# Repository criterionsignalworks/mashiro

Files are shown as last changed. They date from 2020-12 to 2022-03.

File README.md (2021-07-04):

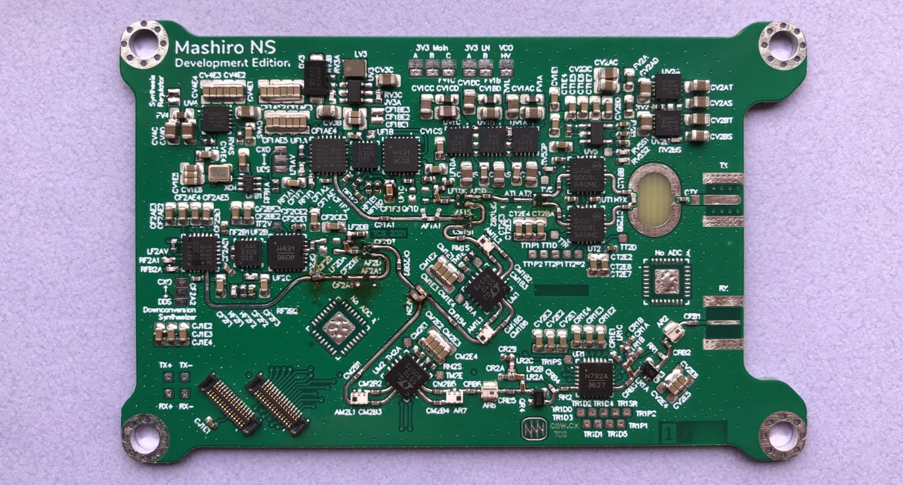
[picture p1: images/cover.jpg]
 

# Project Mashiro 

Explore synthetic aperture radar imaging by building real hardware. 

Currently working on RF front end, processing algorithm, and programming microcontrollers. 

## Abstract 

The ability for autonomous robots to understand their surroundings is instrumental for their ability to interact and navigate the environment safely and effectively. Current autonomous platforms rely heavily on LIDAR and optical camera sensors due their high resolution, compact form factor, and integration accessibility. 

In emergent applications for robotics like search and rescue as well as situations that push the envelope within mainstream applications, harsh environmental conditions like dust, rain, fog, or snow limit the performance of contemporary optical sensor suites. 

Radar imaging uses lower frequencies with wavelengths in the millimeter to centimeter range, while optical methods utilize wavelengths in the hundreds of nanometer range. The longer wavelength of radiofrequency sensing increases dependability in certain situations at the expense of yielding inferior resolution. 

Our system operates at 5.8 GHz for improved immunity from environmental interference compared to typical 77 GHz automotive systems, as well as increased resolution from radar platforms that operate at an even lower frequency. We also apply Synthetic Aperture Radar imaging technique to enhance effective resolution by utilizing the motion of the platform to synthesize a larger virtual aperture aided by computation in hardware. 

We developed an alternative radar architecture featuring two independent synthesizers and downconverters which allow much greater flexibility and performance compared to existing systems which produce baseband at near zero frequency. Our platform is also physically compact, economical, and flexible in realization, which makes it suitable for deployment in size constrained applications and easily extended to fit specific use cases. 

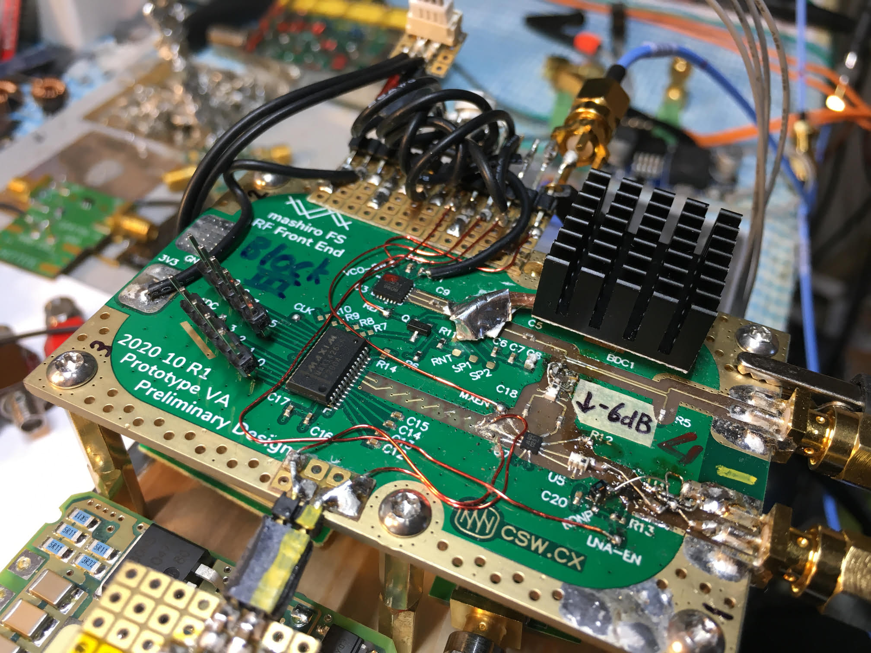
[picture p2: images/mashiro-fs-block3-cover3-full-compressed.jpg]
 

## Current status 

As of March 2021, we have begun additional exploration and development of a processing script for data captured from analog front end. Current plans include use of range migration algorithm presented in §10 of *Spotlight Synthetic Aperture Radar* with modifications to motion correction element. Additionally, we developed [CS Gain Block](https://github.com/criterionsignalworks/gain-block) for rapid prototyping the receive section for our next hardware iteration. 

As of February 2021, we have demonstrated basic remote sensing capabilities with our hardware. We are able to detect motion up to about 7 meters (limited by testing environment) in FMCW mode, and effectively around 5 meters in CW (doppler) mode. 

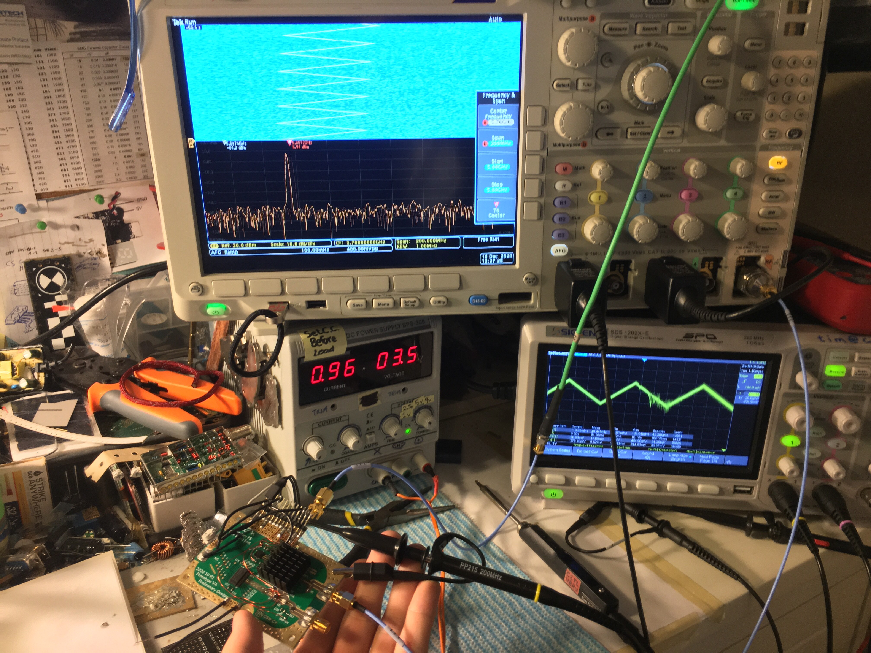
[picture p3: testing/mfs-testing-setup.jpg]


As of late December 2020, we have demonstrated the capability of our high speed analog front end, successfully transmitting a frequency modulated carrier waveform and observing some frequency mixing by the receive section. Additionally, we have begun preliminary prototyping of the digital control, sequencing, and data acquisition systems using our in-house STM32 based microcontroller development platform [CS Ranka](https://github.com/criterionsignalworks/ranka). We have verified the viability of our software development toolchain, using IAR Systems Embedded Workbench development environment. 

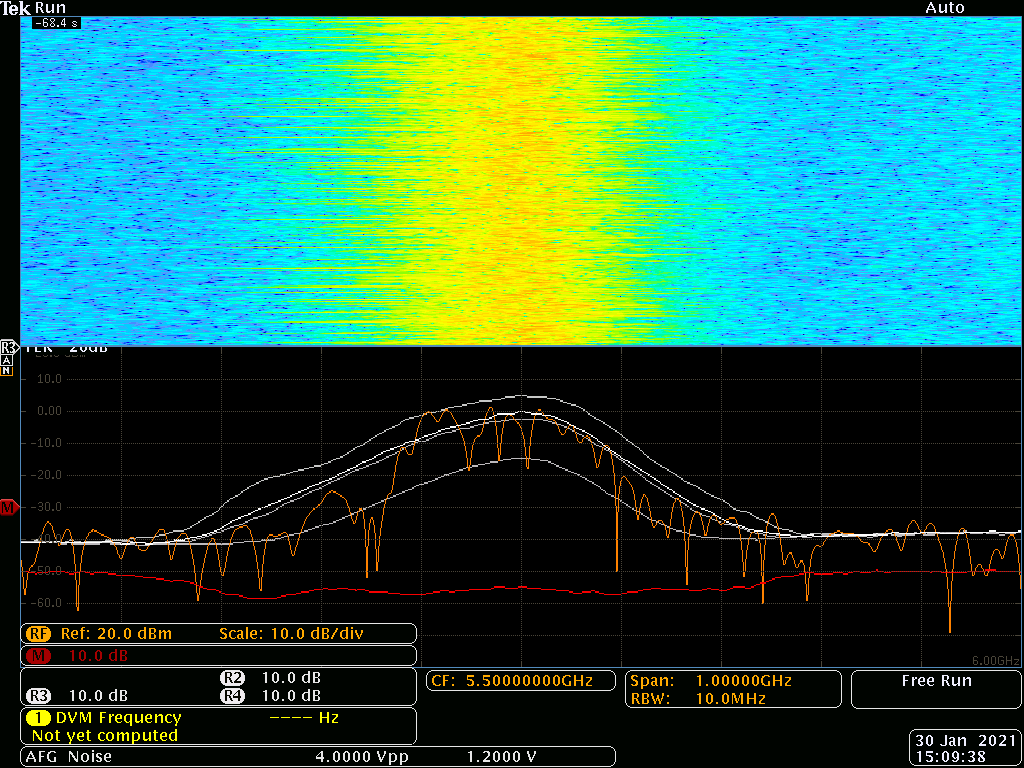
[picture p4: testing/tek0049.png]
 

Project and repository are work in progress, more updates coming some time soon.

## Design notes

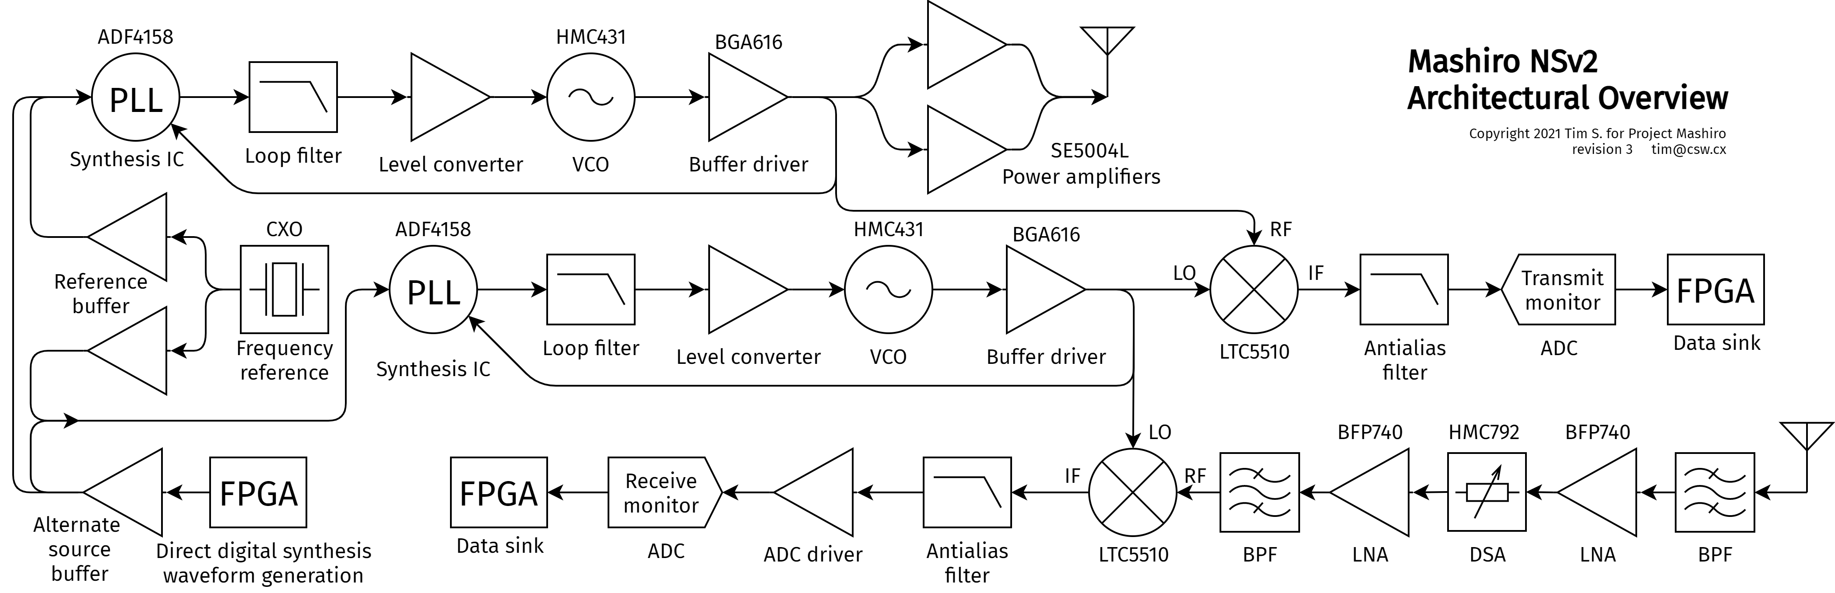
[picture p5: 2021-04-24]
images/mashiro-nsv2-block-diagram-r3.png

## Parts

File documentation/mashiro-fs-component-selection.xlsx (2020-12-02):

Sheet: BOM
CSW Design Documentation |  | CS Mashiro - Mashiro FS Component Selection
TCS July 2020 |  | Selected components
Power amplifier | SE5004L | $2.58 | Max RF input 6dBm
LNA | SKY65404 | $0.50
VCO | HMC431LP4 | $20.00 | Pout 2dbm
MCU | STM32F722RET6 | $6.00
ADC Option 1 | AD9200 | $7.00 | ???????????
ADC Option 2 | MAX1426 | $5.00
Analog front end? | AFE5401 | $23.00
Baseband amplifier | LT6230/LT6232 | $4.00
Baseband amplifier | LT6237 | $4.00
Baseband amplifier | TLV3541 | $0.80
Rx band select filter | DEA205425BT | $0.16 | https://lcsc.com/product-detail/RF-Filters_TDK_DEA205425BT-2028A4_DEA205425BT-2028A4_C136229.html
Heterodyning mixer | ADL5801 | $11.00 | used in fmcw2
Heterodyning mixer | LTC5562 | $12.00 | performance looks good

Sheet: Signal Chains
VCO (POUT: 2dbm)
Power AMP (6dbm)
Component | In Min | In Max | In N/A | Out Min | Out Max | Out N/A
VCO |  |  |  | -1dbm | 2dbm
Power AMP | 6dbm

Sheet: ADC
 | CSW Design Documentation |  | CS Mashiro - Mashiro FS Component Selection
 | TCS July 2020 |  | Signal digitization - ADC
 | Design target: 12-bit, 80MHz
 | MAX1426 | AD9200 | 3PA1030 | ADC12020 | ADC08351 | ADC1173
Est. Unit cost (1@10) | $5.00 | $7.00 | $2.50 | $4.20 | $2.00 | $3.00
Manufacturer | Maxim | Analog Devices | 3PEAK | TI/National Semi | TI/National Semi | TI
Bit depth | 10 bit | 10 bit | 10 bit | 12 bit | 8 bit | 8 bit
Sample rate | 10 Msps | 20 Msps | 50 Msps? | 20 Msps | 42 Msps | 15 Msps

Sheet: MCU
 |  | CSW Design Documentation |  | CS Mashiro - Mashiro FS Component Selection
 |  | TCS July 2020 |  | Computation and communication - MCU/Microcontroller
 |  | MKL26Z | STM32F103C8T6 | STM32F722RET6 (https://lcsc.com/product-detail/ST-Microelectronics_STMicroelectronics_STM32F722RET6_STM32F722RET6_C118207.html) | LPC4320 | ESP32-PICO-D4
 | Est. Unit cost (1@10) |  |  | $5.13 | $7.60
 | Manufacturer | NXP/Kinetis | STMicroelectronics | STMicroelectronics | NXP | Espressif
 | Family/Toolchain |  | STM32 | STM32 |  | ESP32
 | Core architecture |  | Cortex M3 | Cortex M7 | Cortex M4/M0 | 2x Xtensa LX6
 | Frequency |  | 72MHz | 216MHz | 204MHz | 240MHz
 | Package |  | LQFP-48
Memory | Flash |  | 64KB/128KB | 512KB | 0KB | 448KB
 | SRAM |  | 20KB | 256KB | 256KB | 8KB + 8KB
 | EEPROM
Comms | USART |  | 3x |  |  | 3x
 | I2C |  | 2x 18Mbit/s | 3x |  | 3x 80MHz
 | SPI |  | 2x |  |  | 2x 400kbit/s
 | USB |  | 2.0 FS
 | CAN

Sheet: RF Amplifiers
 | CSW Design Documentation |  | CS Mashiro - Mashiro FS Component Selection
 | TCS July 2020 |  | Amplifiers
 | Design target: may vary
 | MGA-25203 (https://np.infinity-electronic.hk/datasheet/8d-MGA-25203-TR1G.pdf) | BGA622 (https://lcsc.com/product-detail/RF-Amplifiers_Infineon-Technologies_BGA622H6820_Infineon-Technologies-BGA622H6820_C132318.html) | TQP7M9101 (https://lcsc.com/product-detail/RF-Amplifiers_Qorvo-TQP7M9101_C415713.html) | SE5004L (https://lcsc.com/product-detail/Others_Skyworks-Solutions_SE5004L-R_Skyworks-Solutions-SE5004L-R_C210263.html) | SKY65404 (https://lcsc.com/product-detail/Others_Skyworks-Solutions_SKY65404-31_Skyworks-Solutions-SKY65404-31_C210262.html) | SST11LP12 (http://ww1.microchip.com/downloads/en/DeviceDoc/75047A.pdf)
Applicaton | PA | LNA | Gain block | PA | LNA | PA
Est. Unit cost (1@10) |  | $0.39 | $1.96 | $2.58 | $0.50
Manufacturer | Avago | Infineon | Qorvo | Skyworks | Skyworks | SST/Microchip
Band | 4.9-5.9 GHz |  | 0.4-5 GHz |  | 4.9-5.9 GHz | 4.9-5.9 GHz
Gain/output | 30 dB (5.4GHz 3V3) 32 dBm (64QAM) |  | 17.5 dB gain @2.14 25 dBm P1dB | 32 dB gain 3% EVM @26 dBm | 7 dBm IIP3 13 dB gain | 3% EVM 20dBm 31 dB gain @5.4
Noise figure |  | 1 dB at 1.575 GHz |  |  | 1 dB
Impedance | 50Ω |  | Matched(?)
Supply voltage | 3-5V |  | 5V | 3-5.5V (Vref 2.85V) | 2.8-5V
Gain flatness | <1dB, any 20MHz | Not PA

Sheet: Baseband Amplifiers
 | CSW Design Documentation |  | CS Mashiro - Mashiro FS Component Selection
 | TCS July 2020 |  | Amplifiers
 | Design target: may vary
 |  | Est. Cost | Manufacturer | Max BW (Unity) | Noise | Slew rate | CMR | R-R capability
range comp IF amp | LT6230/LT6232 (https://www.analog.com/media/en/technical-documentation/data-sheets/623012fc.pdf) | $4.00 | LT | 215MHz | 1.1nV/√Hz | 70V/us | 90-115dB | Yup
 | LT6236 (https://datasheet.octopart.com/LT6236CS6%23TRMPBF-Linear-Technology-datasheet-32866028.pdf) | $4.00 | LT | 215MHz | 1.1nV/√Hz | 70V/us | 90-115dB | Yup
 | LM318MX (https://lcsc.com/product-detail/General-Purpose-Amplifiers_Texas-Instruments_LM318MX-NOPB_Texas-Instruments-Texas-Instruments-LM318MX-NOPB_C128749.html) | $0.80 | TI | 15MHz |  | 50V/us |  | No?
 | LM358DT (https://lcsc.com/product-detail/General-Purpose-Amplifiers_STMicroelectronics-LM358DT_C9418.html) | $0.05 | ST | 1.1MHz |  |  |  | No
fmcw2 adc | LT1817 (https://www.analog.com/media/en/technical-documentation/data-sheets/181567fb.pdf) | $3.70 | LT | 220MHz | 6nV/√Hz | 1500V/us
 | ADA4891-1 (https://www.analog.com/media/en/technical-documentation/data-sheets/ADA4891-1_4891-2_4891-3_4891-4.PDF) | $1.50 | AD | 220MHz (-3dB) | 9nV/√Hz | 170V/us |  | Yes | + | low cost
 | LT1722 (https://www.analog.com/media/en/technical-documentation/data-sheets/172234fb.pdf) | $2.80 | LT | 220MHz | 3.8nV/√Hz | 70V/us |  |  | + | rf amp
 | ADA4807-1 (https://www.analog.com/media/en/technical-documentation/data-sheets/ADA4807-1_4807-2_4807-4.pdf) | $4.70 | AD | 180MHz (-3dB) | 3.1nV/√Hz | 225V/us |  | Yes
 | AD8057 (https://www.analog.com/media/en/technical-documentation/data-sheets/AD8057_8058.pdf) | $2.60 | AD | 325MHz (-3dB) | 7nV/√Hz | 1000V/us
 | TLV3541 (https://www.ti.com/lit/ds/symlink/tlv3541.pdf?ts=1596304995804) | $0.80 | TI | 200MHz Unity | 7.5nV/√Hz | 150V/us |  | Yes | + | low cost

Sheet: CPLD
 | CSW Design Documentation |  | CS Mashiro - Mashiro FS Component Selection
 | TCS July 2020 |  | Front side signal processing - FPGA
 | EPM3032A (https://lcsc.com/product-detail/New-Arrivals_Altera-EPM3032ATC44-10N_C500865.html)
Est. Unit cost (1@10) | $1.96
Manufacturer | Altera
Family/Toolchain | MAX3000A | MachXO2
IO voltage | 5V, 3V3, 2V5
Package logical voltage | 3V3
Clock speed | 227.3MHz
Chosen package | TQFP-44
Min. Pin to pin logic delay | 4.5ns
Logic cells | 600(?)
Macrocell count | 32
Logic array blocks | 2

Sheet: Moonshot
ADC | https://www.analog.com/en/products/ltc2226.html#product-samplebuy
 | https://www.analog.com/en/products/ltc2227.html#product-samplebuy
 | https://www.analog.com/en/products/ltc1745.html#product-samplebuy
VCO | https://www.analog.com/en/products/hmc431.html#product-discussions

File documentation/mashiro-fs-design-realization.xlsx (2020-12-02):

CSW.cx - TCS 2020 - Mashiro FS Design Realization |  |  |  |  |  |  |  |  |  |  |  |  | + | ? | = | X | * |  | W
 |  |  |  |  |  | Supply |  |  | Approval |  |  | Library |  |  |  |  | Schematic |  |  |  | PCB |  |  |  | Fabrication
Component | Function | Confidence | Comment & Notes | Ballpark price | Ballpark qty | Selection | Procurement | Check | TCS | PS | Check | Footprint | Schematic | Symbol | Check |  | Essential | Functional | Other | Check | Placement | Route | Gloss | Check | Physical | SMT Align | SMT Paste clear | Final | Check
STM32F722RET6 | Orchestration | + | SMT or rework? | $7.08 | 1 | + | LC | + | + | + | + | + | + | + | + |  | + | X | X | X | X | X | X | X | X | ? |  | X | X
HMC431LP4 | VCO | + |  | Sample | 1 | + | + | + | + | + | + | + | + | + | + |  | + | + | X | X | X | X | X | X | X | * | X | X | X
SKY65404 | LNA | + |  | $0.59 | 1 | + | SM | + | + | + | + | + | + | + | + |  | + | + | X | X | X | X | X | X | X | X | * | X | X
SE5004L | Tx PA | + |  | $2.97 | 1 | + | SM | + | + | + | + | + | + | + | + |  | + | + | X | X | X | X | X | X | X | X | * | X | X
LTC2227 | ADC | W | Selection in progress |  | 1 | ? | ? | ? | + | = | = | X | X | X | X |  | X | X | X | X | X | X | X | X | X | * | X | X | X
MAX1426 | ADC | + |  | Sample | 1 | + | + | + | + | = | = | + | + | + | + |  | X | X | X | X | X | X | X | X | X | * | X | X | X
LTC5562 | Mixer | W |  |  | 1 | = | W | X | + | = | = | + | + | + | + |  | + | + | X | X | X | X | X | X | X | * | X | X | X
TLV3541 | Opamp | + |  |  | 6? | + | AR | + | + | + | + | + | + | + | + |  | X | X | X | X | X | X | X | X | X | * | X | X | X
2mm Header | Interconnect | + |  | $0.14 | 1 | + | LC | + | + | + | + | + | + | + | + |  | + | X | X | X | X | X | X | X | X | * | X | X | X
Reverse coupler | Microstrip element | * |  | X |  | * | * | * | + | * | + | + | + | + | + |  | + | + | X | X | X | X | X | X | X | * | X | X | X
Mitered corner | Microstrip element | * |  | X |  | * | * | * | + | * | + | + | + | + | + |  | X | X | X | X | X | X | X | X | X | * | X | X | X
HHM1595A1 | Balun | + |  | $0.16 | 2 | + | LC | + | + | + | + | + | + | + | + |  | + | X | X | X | X | X | X | X | X | * | X | X | X
Generic 0402 | R and C Passives | * |  | Varies |  | * | SM | * | + | * | + | + | + | + | + |  | X | X | X | X | X | X | X | X | X | X | * | X | X
Generic SMA | RF connector | * |  | $2.00 | 3 | * | LC | * | + | * | + | + | + | + | + |  | + | + | X | X | X | X | X | X | X | * | X | X | X
XT30PW-M | Power interconnect | + |  | $0.59 | 1 | + | LC | + | + | + | + | + | + | + | + |  | X | X | X | X | X | X | X | X | X | * | X | X | X
C27667 | Mechanical standoff | + |  | $0.20 | 4 | + | LC | + | + | + | + | * | * | * | * |  | X | X | X | X | X | X | X | X | X | * | X | X | X
DSS4240T | NPN Transistor | ? | General purpose | $0.07 | 8? | + | SM | + | + | = | = | + | + | + | + |  | X | X | X | X | X | X | X | X | X | * | X | X | X
NCE3400 | N-Ch En MOSFET | ? | General purpose | $0.04 | 8? | + | SM | + | + | = | = | + | + | + | + |  | X | X | X | X | X | X | X | X | X | X | * | X | X
LDL1117S33R | 3V3 LDO | = | Evaluate options |  | 3? | + | LC | + | + | + | + | + | + | + | + |  | X | X | X | X | X | X | X | X | X | * | X | X | X
NCP51460 | 3V3 reference | + |  | $0.39 | 1 | + | LC | + | + | + | + | + | + | + | + |  | X | X | X | X | X | X | X | X | X | * | X | X | X
S34ML02G200TFI000 | External flash | + |  | $2.11 | 1 | + | SM | + | + | + | + | + | + | + | + |  | X | X | X | X | X | X | X | X | X | X | * | X | X

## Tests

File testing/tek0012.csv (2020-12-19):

Model | MDO4104C
Firmware Version | 1.06
Waveform Type | RF_FD
Point Format | Y
Horizontal Units | Hz
Horizontal Scale | 2e+07
Sample Interval | 200000
Record Length | 1001
Gating | 0.099900099900% to 100.0%
Probe Attenuation | 1
Vertical Units | dBm
Vertical Offset | 0
Vertical Scale | 10
Vertical Position | 0
Center Frequency | 5.7e+09
Span | 2e+08
Reference Level | 20
Label
FREQUENCY | FD NORM
5.6000000000e+09 | -51.4361
5.6002000000e+09 | -53.8631
5.6004000000e+09 | -59.4895
5.6006000000e+09 | -93.7549
5.6008000000e+09 | -60.6486
5.6010000000e+09 | -56.2574
5.6012000000e+09 | -55.0091
5.6014000000e+09 | -55.4714
5.6016000000e+09 | -57.2963
5.6018000000e+09 | -60.5337
5.6020000000e+09 | -64.7291
5.6022000000e+09 | -63.9905
5.6024000000e+09 | -59.6587
5.6026000000e+09 | -56.4418
5.6028000000e+09 | -54.3321
5.6030000000e+09 | -53.064
5.6032000000e+09 | -52.4946
5.6034000000e+09 | -52.6135
5.6036000000e+09 | -53.6617
5.6038000000e+09 | -56.4321
5.6040000000e+09 | -62.8414
5.6042000000e+09 | -58.8765
5.6044000000e+09 | -51.7608
5.6046000000e+09 | -47.8729
5.6048000000e+09 | -45.7339
5.6050000000e+09 | -44.82
5.6052000000e+09 | -44.9162
5.6054000000e+09 | -45.9218
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

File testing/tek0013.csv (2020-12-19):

Model | MDO4104C
Firmware Version | 1.06
Waveform Type | RF_FD
Point Format | Y
Horizontal Units | Hz
Horizontal Scale | 2e+07
Sample Interval | 200000
Record Length | 1001
Gating | 0.099900099900% to 100.0%
Probe Attenuation | 1
Vertical Units | dBm
Vertical Offset | 0
Vertical Scale | 10
Vertical Position | 0
Center Frequency | 5.7e+09
Span | 2e+08
Reference Level | 20
Label
FREQUENCY | FD NORM
5.6000000000e+09 | -45.611
5.6002000000e+09 | -45.9254
5.6004000000e+09 | -45.9914
5.6006000000e+09 | -45.751
5.6008000000e+09 | -45.3121
5.6010000000e+09 | -44.9281
5.6012000000e+09 | -44.907
5.6014000000e+09 | -45.5427
5.6016000000e+09 | -47.1292
5.6018000000e+09 | -50.0363
5.6020000000e+09 | -54.586
5.6022000000e+09 | -57.7789
5.6024000000e+09 | -55.5052
5.6026000000e+09 | -54.0867
5.6028000000e+09 | -54.8188
5.6030000000e+09 | -57.8408
5.6032000000e+09 | -63.008
5.6034000000e+09 | -62.3771
5.6036000000e+09 | -58.5776
5.6038000000e+09 | -56.5913
5.6040000000e+09 | -55.3769
5.6042000000e+09 | -54.0945
5.6044000000e+09 | -52.8397
5.6046000000e+09 | -52.1839
5.6048000000e+09 | -52.599
5.6050000000e+09 | -54.5112
5.6052000000e+09 | -58.0869
5.6054000000e+09 | -58.4334
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

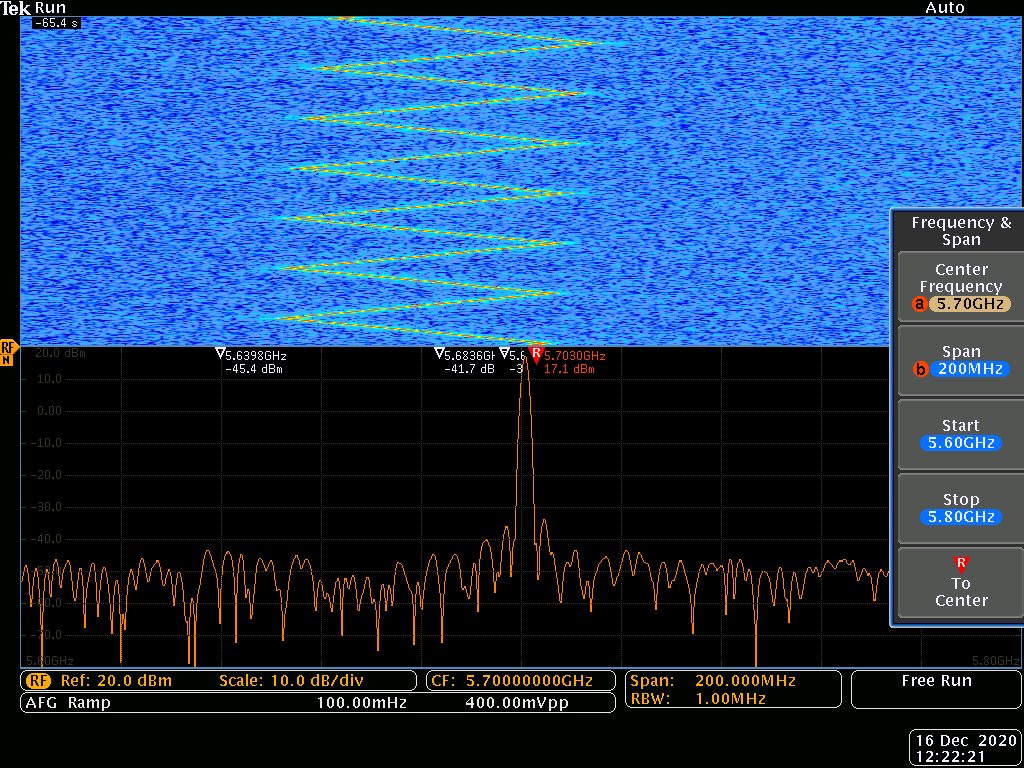
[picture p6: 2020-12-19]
testing/fs-tx-ramp-no-att.png

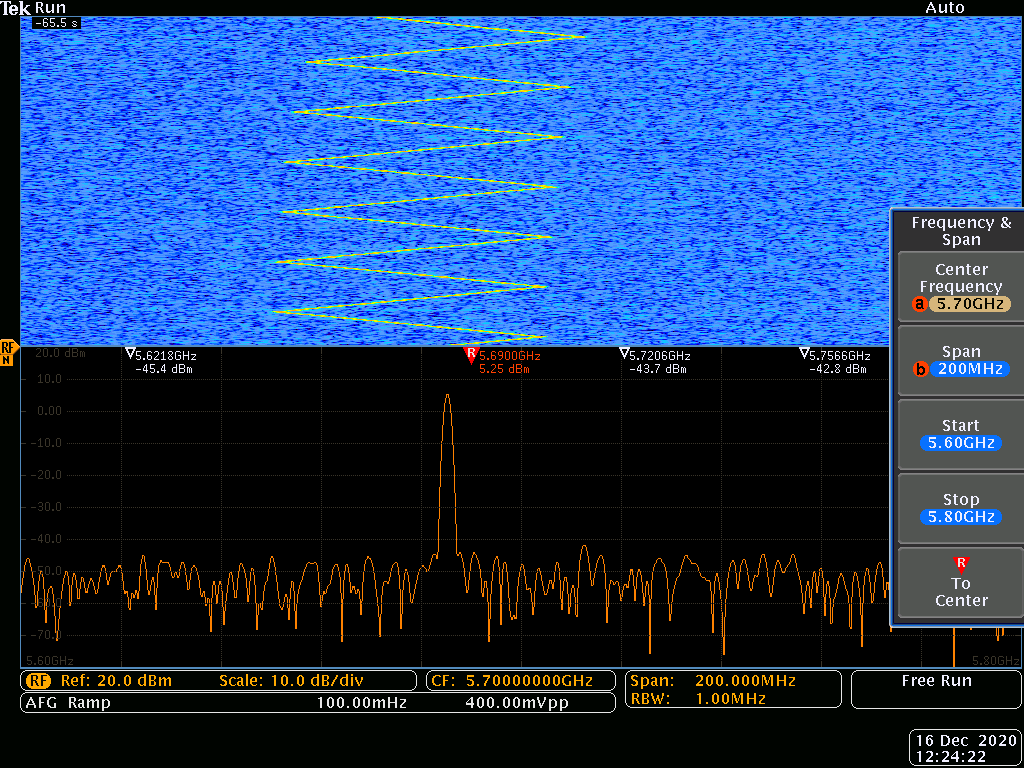
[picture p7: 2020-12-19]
testing/fs-tx-ramp-att-drift.png

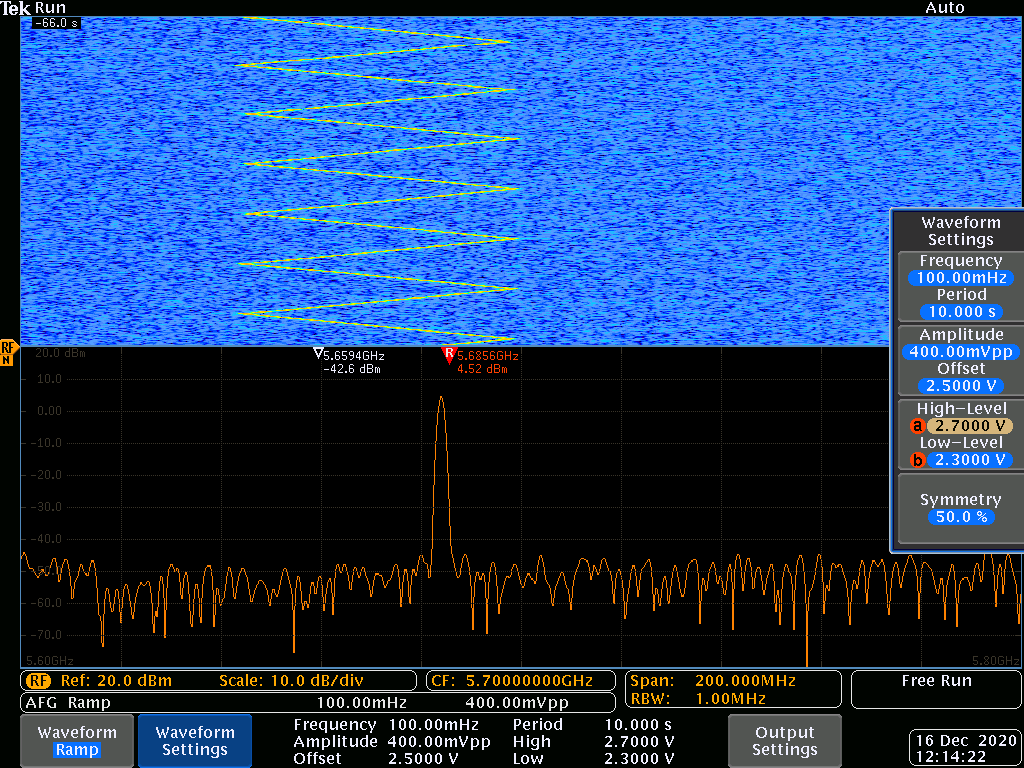
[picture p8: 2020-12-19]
testing/fs-tx-ramp-att.png

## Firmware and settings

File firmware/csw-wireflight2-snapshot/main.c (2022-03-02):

/*

csw-wireflight
Ground up programming blink demo

IAR EW project for Ranka N1 and compatible.

Property of Criterion Signalworks.
Do not distribute or reproduce without permission.
For more information, contact management@csw.cx or tim@csw.cx

TCS 2020 10

*/

#include <stdint.h>

unsigned long sy; 

// PB BASE 0x40020400
// PB MODER 0x00000000, 01 = GP output
// PB ODR 0x00000014
// TIM2 boundry 0x4000 0000 - 0x4000 03FF 
// TIMx PSC offset 0x28
// TIMx ARR offset 0x2C - reset 0xFFFF FFFF high / low byte
// TIMx interrupt enable / DMA offset 0x0C - UIE (update enable) at bit 0 
// TIMx master enable (CEN) at bit 0 of CR1 offset 0x00 reset 0x0000 - write 0x0001 to enable 
// because its at the end ok 
// hello hello SR pending update at bit 0 offset 0x10 (UIF) yes ok 
// tim2 global interrupt addr 0x0000 00B0 position 28 priority 35 

volatile uint32_t *M = (volatile uint32_t *)0x40020400;
volatile uint32_t *O = (volatile uint32_t *)0x40020414;
volatile uint32_t *T2ARR = (volatile uint32_t *)0x4000002C;
volatile uint32_t *T2PSC = (volatile uint32_t *)0x40000028;
volatile uint32_t *T2hello = (volatile uint32_t *)0x4000000C;
volatile uint32_t *T2hi = (volatile uint32_t *)0x40000000;
volatile uint32_t *T2re = (volatile uint32_t *)0x40000010;
volatile uint32_t *coolest = (volatile uint32_t *)0xE000E100UL;

void delay(unsigned long tg){
  tg = tg- 1;
  unsigned long lm = sy + tg;
  while(lm >= sy);
}

void inittim2()			//  Setup Timer 2 to generate an interrupt every 1mS based on a 16MHz clock. (copied from coda)
{
    *T2PSC = 0x05;		//  prescaler is 32.
    *T2ARR = 0x000001f4; 	// is this correct?????
    *T2hello = 0x1;		//  enable update interrupt by writing 1 to UIE
    *T2hi = 0x1;		//  enable timer by writing 1 to CEN
}

/*
#pragma vector = 28
__interrupt void TIM2_IRQHandler(void) {
    sy++;			//  timer increment
    *T2re = 0x0;		//  no more interrupt!!!!!!!!!!!!!!!!!!!!!!  
}

// NVIC ISER 0xE000E100UL
// 1   0    0   0    0   0    0   0 
// 00010000 00000000 00000000 00000000
*/





int main()
{
	*coolest = 0x10000000;
	*M = 0x55;
	while(1) {
	*O = 0x00;
	*O = 0xFF;
	}
}

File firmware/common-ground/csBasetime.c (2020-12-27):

/*

csBasetime.c
Basic timer function and system clock configuration 

IAR EW library for Coda 0.6/0.7 and compatible.

Property of Criterion Signalworks.
Do not distribute or reproduce without permission.
For more information, contact management@csw.cx or tim@csw.cx

TCS 2020 12

*/

#include <iostm8S103f3.h>

void csInitSysClk() {			// Initialize SysClk
	CLK_ICKR = 0;			//  Reset the Internal Clock Register
	CLK_ICKR_HSIEN = 1;		//  Enable the HSI
	CLK_ECKR = 0;			//  Disable the external clock
	while (CLK_ICKR_HSIRDY == 0);	//  Wait for the HSI to be ready for use
	CLK_CKDIVR = 0;			//  Ensure the clocks are running at full speed
	CLK_PCKENR1 = 0xff;		//  Enable all peripheral clocks
	CLK_PCKENR2 = 0xff;
	CLK_CCOR = 0;			//  Turn off CCO
	CLK_HSITRIMR = 0;		//  Turn off any HSIU trimming
	CLK_SWIMCCR = 0;		//  Set SWIM to run at clock / 2
	CLK_SWR = 0xe1;			//  Use HSI as the clock source
	CLK_SWCR = 0;			//  Reset the clock switch control register
	CLK_SWCR_SWEN = 1;		//  Enable switching
	while (CLK_SWCR_SWBSY != 0);	//  Pause while the clock switch is busy
}

unsigned long csDelayMsSysTick = 0;

void csDelayMs(unsigned long csDelayMsTarget){
  csDelayMsTarget = csDelayMsTarget- 1;
  unsigned long csDelayMsLimit = csDelayMsSysTick + csDelayMsTarget;
  while(csDelayMsLimit >= csDelayMsSysTick);
}

//  TIM2 interrupt handler for delay function 
#pragma vector = TIM2_OVR_UIF_vector
__interrupt void TIM2_UPD_OVF_IRQHandler(void)
{
	csDelayMsSysTick++;		//  System tick increment
	TIM2_SR1_UIF = 0;		//  Reset the interrupt
}

void csInitDelayMs() {		//  Setup Timer 2 to generate an interrupt every 1mS based on a 16MHz clock.
	TIM2_PSCR = 0x04;		//  Prescaler = 32. actually 16
	TIM2_ARRH = 0x03;		//  High byte of 940. 
	TIM2_ARRL = 0xe6;		//  Low byte 
	TIM2_IER_UIE = 1;		//  Enable the update interrupts.
	TIM2_CR1_CEN = 1;		//  Finally enable the timer.
}

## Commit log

2020-12-02 Add files
    From CSW Internal directory - documentation and design files for mashiro FS
    [Mashiro FS (release).PcbDoc, mashiro-fs-component-selection.xlsx, mashiro-fs-design-realization.xlsx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]
2020-12-19 add assets from testing transmit section
    From 2020 12/16 noon ish. Images, spectrum data, and scope settings
    [tek0012.csv, tek0013.csv, tek0014.csv]
2020-12-27 add wireflight2-snapshot to firmware
    this code is from october 2020, just putting it in now as a more official experimental version
2020-12-27 add cs common ground library
    snapshot version 20201212.13
2021-03-17 Update currently working
2021-03-17 add capture from vna - honoring don's naming here
    [tim.csv]
2021-04-20 removed YT link (video currently private)
